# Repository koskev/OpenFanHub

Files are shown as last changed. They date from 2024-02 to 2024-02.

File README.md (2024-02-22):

# OpenFanHub

This project aims to provide plug and play solution for controlling fans and reading temperatures

## Attention
 * The USB-Library is licensed under the SLA0044 License and therefore incompatible with the GPL. Until this is resolved the GPL does not apply to the "Firmware" folder.

## TODO
 * Finish PCB
   * Currently working on a barebone blue pill
   * Probably remove the option for two different µC options
 * Replace USB Lib
 * Implement Rust version as a learning experience?
   * But currently USB hates me :/
 * Replace the USB lib to be compatible with an open source license

## Features
 * Connection for 18 fans
    * 3 Fans form one group
    * 6 independently controllable
    * only one fan in each group reports rpm
    * 3 pin fans are supported but not regulated (I tried it, but ended but beeing to complicated since I plan on using 4 pin anyways)
 * 4 thermistor inputs
 * compatible with the corsair commander pro driver of the kernel
 * Compatible with the "blue pill" boards or an stm32f103c8tx in an LQFP48 package
    * The goal is to make is easy to solder and LQFP48 can be hard

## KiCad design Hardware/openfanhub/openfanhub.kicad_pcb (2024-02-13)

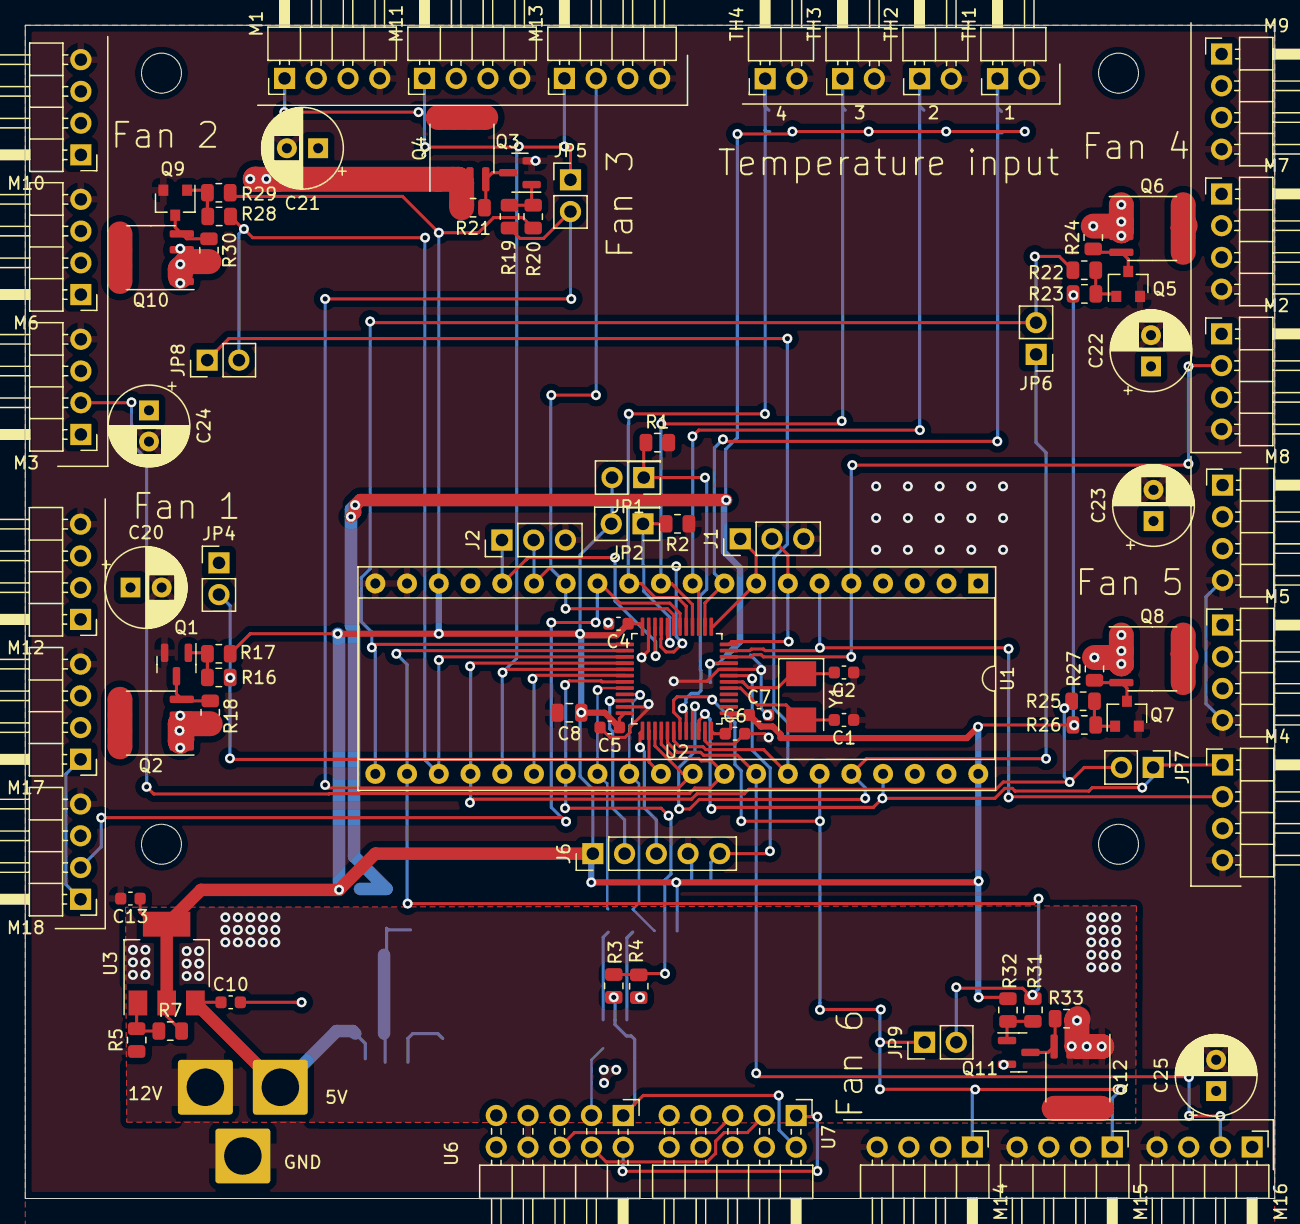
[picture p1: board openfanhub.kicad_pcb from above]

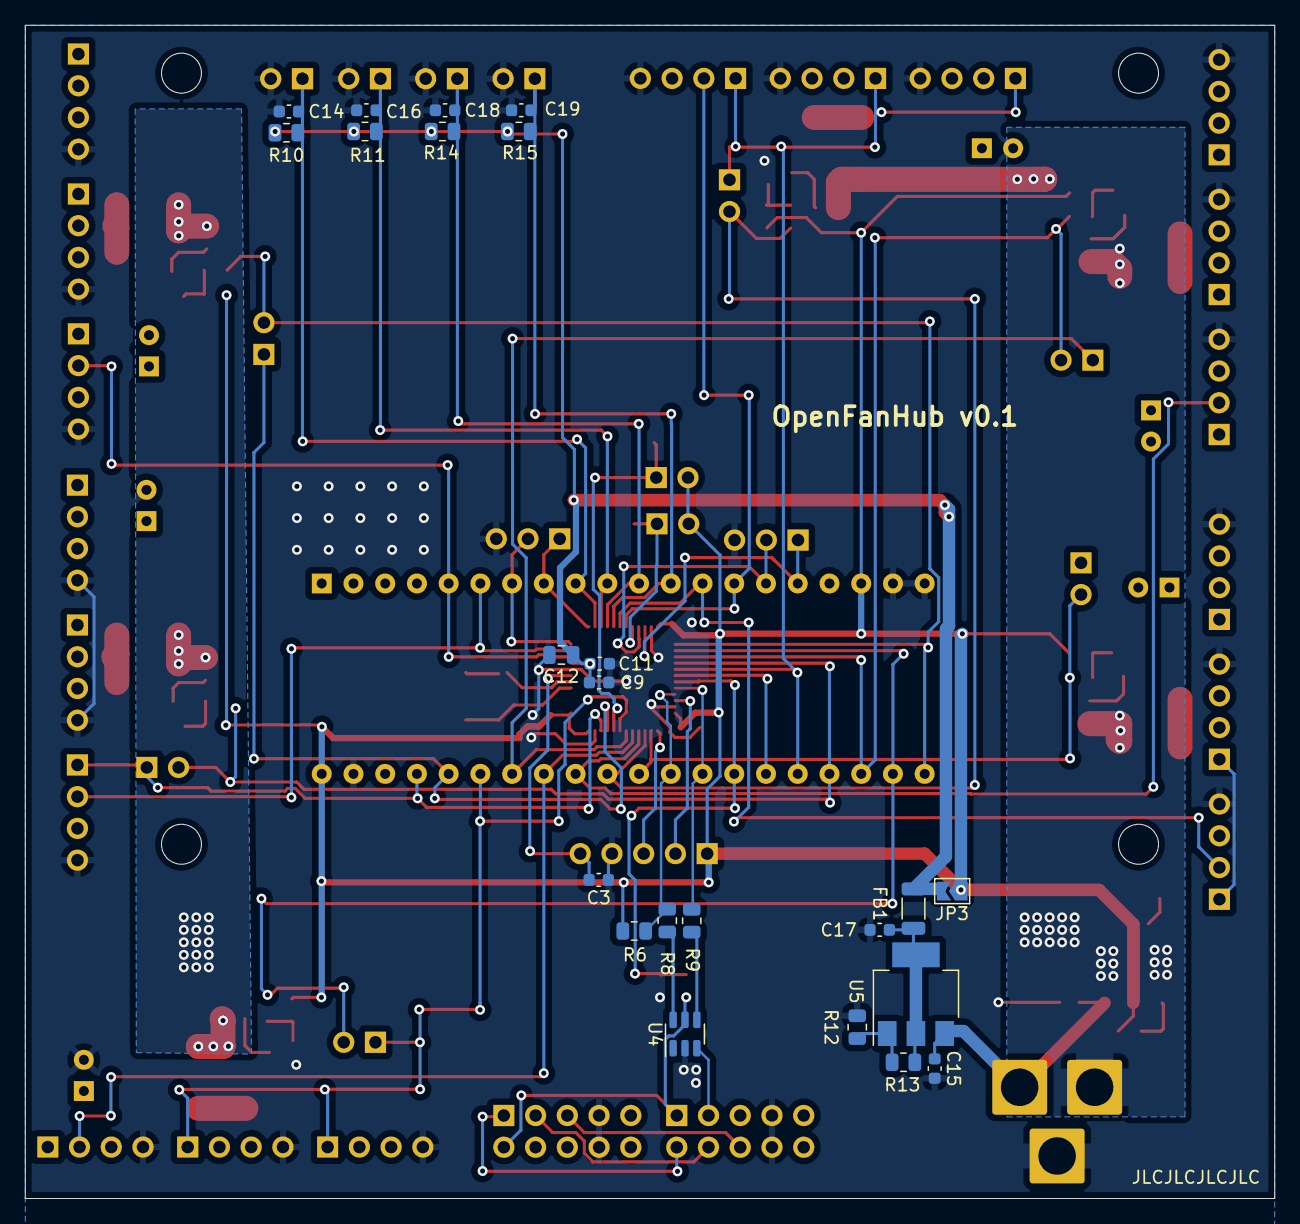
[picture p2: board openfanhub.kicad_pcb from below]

Board: 2 copper layers, 100.0 x 93.9 mm, 120 parts (23 on the bottom side), 70 nets.

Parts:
C1, C2: 22pF; C_0603_1608Metric
C3, C4, C5, C6, C7, C9: 100nF; C_0603_1608Metric
C8, C12: 10µF; C_0805_2012Metric
C10, C13, C14, C15, C16, C17, C18, C19: C; C_0603_1608Metric
C11: 10nF; C_0603_1608Metric
C20, C21, C22, C23, C24, C25: C_Polarized; CP_Radial_D6.3mm_P2.50mm
FB1: FerriteBead; L_1206_3216Metric
H1, H2, H3, H4: MountingHole; MountingHole_3.2mm_M3
J1: UART; PinHeader_1x03_P2.54mm_Vertical
J2: I2C; PinHeader_1x03_P2.54mm_Vertical
J3: 12V in; SolderWire-2.5sqmm_1x01_D2.4mm_OD4.4mm
J4: GND in; SolderWire-2.5sqmm_1x01_D2.4mm_OD4.4mm
J5: 5V IN; SolderWire-2.5sqmm_1x01_D2.4mm_OD4.4mm
J6: SWD; PinHeader_1x05_P2.54mm_Vertical
JP1, JP2: Jumper_2_Open; PinHeader_2x01_P2.54mm_Vertical
JP3: 3.3V connect; SolderJumper-2_P1.3mm_Open_TrianglePad1.0x1.5mm
JP4, JP5, JP6, JP7, JP8, JP9: 3Pin Jumper; PinHeader_1x02_P2.54mm_Vertical
M1, M2, M3, M4, M5, M6, M7, M8, M9, M10, M11, M12, M13, M14, M15, M16, M17, M18: Fan_4pin; PinHeader_1x04_P2.54mm_Horizontal
Q1, Q3, Q5, Q7, Q9, Q11: IRLML2502; SOT-23
Q2, Q4, Q6, Q8, Q10, Q12: AO4409; SOIC-8_3.9x4.9mm_P1.27mm
R1, R2: 10k; R_0805_2012Metric
R3, R4, R5, R6, R7, R8, R9, R10, R11, R12, R13, R14, R15, R16, R17, R18, R19, R20, R21, R22, R23, R24, R25, R26, R27, R28, R29, R30, R31, R32, R33: R; R_0805_2012Metric
TH1, TH2, TH3, TH4: Thermistor; PinHeader_1x02_P2.54mm_Horizontal
U1: STM32F103C8T8_Board; DIP-40_W15.24mm_Socket
U2: STM32F103C8Tx; LQFP-48_7x7mm_P0.5mm
U3, U5: AMS1117; SOT-223
U4: USBLC6-2SC6; SOT-23-6
U6: USB_HEADER_IN; PinHeader_2x05_P2.54mm_Horizontal
U7: USB_HEADER_OUT; PinHeader_2x05_P2.54mm_Horizontal
Y1: Crystal; Crystal_SMD_5032-2Pin_5.0x3.2mm

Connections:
+3.3VA: C9.1, C11.1, C12.1, FB1.2, JP3.2 (B), R10.1, R11.1, R14.1, R15.1, U2.9 (VDDA)
+3V3: C4.1, C5.1, C6.1, C7.1, C8.1, C13.1, J6.1, JP1.2 (B), JP2.2 (B), JP3.1 (A), R6.2, R7.2, R17.1, R20.1, R23.1, R26.1, R29.1, R32.1, U1.18 (3.3V), U1.40 (3.3V), U2.1 (VBAT), U2.24 (VDD), U2.36 (VDD), U2.48 (VDD), U3.2 (Vout), U3.4 (Vout)
+5V: C10.1, C15.1, J5.1, U3.3 (Vin), U5.3 (Vin)
+12V: J3.1, Q2.1 (S), Q2.2 (S), Q2.3 (S), Q4.1 (S), Q4.2 (S), Q4.3 (S), Q6.1 (S), Q6.2 (S), Q6.3 (S), Q8.1 (S), Q8.2 (S), Q8.3 (S), Q10.1 (S), Q10.2 (S), Q10.3 (S), Q12.1 (S), Q12.2 (S), Q12.3 (S), R18.2, R21.2, R24.2, R27.2, R30.2, R33.2
/BOOT0: JP1.1 (A), R1.1, U2.44 (BOOT0)
/BOOT1: JP2.1 (A), R2.2, U2.20 (PB2)
/D1+: U4.1 (I/O1), U6.5 (D1+)
/D1-: U4.3 (I/O2), U6.3 (D1-)
/FAN1_PWM: JP6.1 (A), M2.1 (PWM), M7.1 (PWM), M9.1 (PWM), U1.36 (B8), U2.45 (PB8)
/FAN1_RPM: M2.2 (Tacho), U1.5 (A0), U2.10 (PA0)
/FAN1_SWITCH: JP6.2 (B), R22.2, U1.21 (B12), U2.25 (PB12)
/FAN2_PWM: JP7.1 (A), M4.1 (PWM), M5.1 (PWM), M8.1 (PWM), U1.37 (B9), U2.46 (PB9)
/FAN2_RPM: M4.2 (Tacho), U1.6 (A1), U2.11 (PA1)
/FAN2_SWITCH: JP7.2 (B), R25.2, U1.24 (B15), U2.28 (PB15)
/FAN3_PWM: JP8.1 (A), M3.1 (PWM), M6.1 (PWM), M10.1 (PWM), U1.34 (B6), U2.42 (PB6)
/FAN3_RPM: M3.2 (Tacho), U1.32 (B4), U2.40 (PB4)
/FAN3_SWITCH: JP8.2 (B), R28.2, U1.23 (B14), U2.27 (PB14)
/FAN4_PWM: JP9.1 (A), M14.1 (PWM), M15.1 (PWM), M16.1 (PWM), U1.35 (B7), U2.43 (PB7)
/FAN4_RPM: M16.2 (Tacho), U1.33 (B5), U2.41 (PB5)
/FAN4_SWITCH: JP9.2 (B), R31.2, U1.22 (B13), U2.26 (PB13)
/FAN5_PWM: JP4.1 (A), M12.1 (PWM), M17.1 (PWM), M18.1 (PWM), U1.26 (A9), U2.30 (PA9)
/FAN5_RPM: M18.2 (Tacho), U1.13 (B0), U2.18 (PB0)
/FAN5_SWITCH: JP4.2 (B), R16.2, U1.30 (A15), U2.38 (PA15)
/FAN6_PWM: JP5.1 (A), M1.1 (PWM), M11.1 (PWM), M13.1 (PWM), U1.25 (A8), U2.29 (PA8)
/FAN6_RPM: M13.2 (Tacho), U1.14 (B1), U2.19 (PB1)
/FAN6_SWITCH: JP5.2 (B), R19.2, U1.31 (B3), U2.39 (PB3)
/NRST: C3.2, J6.5, U2.7 (NRST)
/PWM_GROUPS/PWM_GROUP1/SWITCHED_POWER: C22.1, M2.3 (+), M7.3 (+), M9.3 (+), Q6.5 (D), Q6.6 (D), Q6.7 (D), Q6.8 (D)
/PWM_GROUPS/PWM_GROUP2/SWITCHED_POWER: C23.1, M4.3 (+), M5.3 (+), M8.3 (+), Q8.5 (D), Q8.6 (D), Q8.7 (D), Q8.8 (D)
/PWM_GROUPS/PWM_GROUP3/SWITCHED_POWER: C24.1, M3.3 (+), M6.3 (+), M10.3 (+), Q10.5 (D), Q10.6 (D), Q10.7 (D), Q10.8 (D)
/PWM_GROUPS/PWM_GROUP4/SWITCHED_POWER: C25.1, M14.3 (+), M15.3 (+), M16.3 (+), Q12.5 (D), Q12.6 (D), Q12.7 (D), Q12.8 (D)
/PWM_GROUPS/PWM_GROUP5/SWITCHED_POWER: C20.1, M12.3 (+), M17.3 (+), M18.3 (+), Q2.5 (D), Q2.6 (D), Q2.7 (D), Q2.8 (D)
/PWM_GROUPS/PWM_GROUP6/SWITCHED_POWER: C21.1, M1.3 (+), M11.3 (+), M13.3 (+), Q4.5 (D), Q4.6 (D), Q4.7 (D), Q4.8 (D)
/SCL: J2.2, U1.15 (B10), U2.21 (PB10)
/SDA: J2.1, U1.16 (B11), U2.22 (PB11)
/SWD_CLK: J6.3, U2.37 (PA14)
/SWD_IO: J6.2, U2.34 (PA13)
/TEMP1_IN: C14.1, R10.2, TH1.1, U1.9 (A4), U2.14 (PA4)
/TEMP2_IN: C16.1, R11.2, TH2.1, U1.10 (A5), U2.15 (PA5)
/TEMP3_IN: C18.1, R14.2, TH3.1, U1.11 (A6), U2.16 (PA6)
/TEMP4_IN: C19.1, R15.2, TH4.1, U1.12 (A7), U2.17 (PA7)
/UART_RX: J1.1, U1.8 (A3), U2.13 (PA3)
/UART_TX: J1.2, U1.7 (A2), U2.12 (PA2)
/USB_D+: R6.1, R8.1, U1.29 (A12), U2.33 (PA12)
/USB_D-: R9.1, U1.28 (A11), U2.32 (PA11)
/VBUS: R3.1, U4.5 (VBUS), U6.1 (5V), U7.2 (5V)
/VBUS_SENSE: R3.2, R4.1, U1.27 (A10), U2.31 (PA10)
GND: C1.1, C2.1, C3.1, C4.2, C5.2, C6.2, C7.2, C8.2, C9.2, C10.2, C11.2, C12.2, C13.2, C14.2, C15.2, C16.2, C17.2, C18.2, C19.2, C20.2, C21.2, C22.2, C23.2, C24.2, C25.2, J1.3, J2.3, J4.1, J6.4, M1.4 (-), M2.4 (-), M3.4 (-), M4.4 (-), M5.4 (-), M6.4 (-), M7.4 (-), M8.4 (-), M9.4 (-), M10.4 (-), M11.4 (-), M12.4 (-), M13.4 (-), M14.4 (-), M15.4 (-), M16.4 (-), M17.4 (-), M18.4 (-), Q1.2 (S), Q3.2 (S), Q5.2 (S), Q7.2 (S), Q9.2 (S), Q11.2 (S), R1.2, R2.1, R4.2, R5.1, R12.1, TH1.2, TH2.2, TH3.2, TH4.2, U1.19 (GND), U1.20 (GND), U1.39 (GND), U2.8 (VSSA), U2.23 (VSS), U2.35 (VSS), U2.47 (VSS), U4.2 (GND), U6.7 (GND), U6.8 (GND), U7.7 (GND), U7.8 (GND)
unnamed: C1.2, U2.5 (PD0), Y1.2
unnamed: C2.2, U2.6 (PD1), Y1.1
unnamed: C17.1, FB1.1, R13.2, U5.2 (Vout), U5.4 (Vout)
unnamed: Q1.1 (G), R16.1, R17.2
unnamed: Q1.3 (D), Q2.4 (G), R18.1
unnamed: Q3.1 (G), R19.1, R20.2
unnamed: Q3.3 (D), Q4.4 (G), R21.1
unnamed: Q5.1 (G), R22.1, R23.2
unnamed: Q5.3 (D), Q6.4 (G), R24.1
unnamed: Q7.1 (G), R25.1, R26.2
unnamed: Q7.3 (D), Q8.4 (G), R27.1
unnamed: Q9.1 (G), R28.1, R29.2
unnamed: Q9.3 (D), Q10.4 (G), R30.1
unnamed: Q11.1 (G), R31.1, R32.2
unnamed: Q11.3 (D), Q12.4 (G), R33.1
unnamed: R5.2, R7.1, U3.1 (ADJ)
unnamed: R8.2, U4.6 (I/O1)
unnamed: R9.2, U4.4 (I/O2)
unnamed: R12.2, R13.1, U5.1 (ADJ)
unnamed: U6.2 (5V), U7.1 (5V)
unnamed: U6.4 (D2-), U7.3 (D1-)
unnamed: U6.6 (D2+), U7.5 (D1+)

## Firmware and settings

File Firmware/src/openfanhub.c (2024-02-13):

#include "STM32F1/Drivers/STM32F1xx_HAL_Driver/Inc/stm32f1xx_hal_gpio.h"
#include "adc.h"
#include "stm32f1xx.h"
#include "STM32F1/Drivers/STM32F1xx_HAL_Driver/Inc/stm32f1xx_hal_flash.h"
#include <cmsis_gcc.h>
#include <stm32f103xb.h>
#include <stm32f1xx_hal.h>
#include <stm32f1xx_hal_conf.h>
#include <main.h>
#include <adc.h>
#include <dma.h>
#include <i2c.h>
#include <tim.h>
#include <usart.h>
#include <usb_device.h>
#include <gpio.h>

#include "STM32F1/Inc/usbd_custom_hid_if.h"
#include "stm32f1xx_hal_adc.h"
#include "stm32f1xx_hal_tim.h"

#include <gpio.h>

#include <stdint.h>
#include <string.h>

#include "config.h"

#include "lib/logf.h"

#include "fan.h"

volatile uint16_t temps[4] = {0};

/**
 * Notes Fan:
 * PWM
 * https://www.glkinst.com/cables/cable_pics/4_Wire_PWM_Spec.pdf
 * https://noctua.at/pub/media/wysiwyg/Noctua_PWM_specifications_white_paper.pdf
 * 	25kHz, acceptable range 21kHz to 28kHz
 * 		freq doesn't seem to matter at all. even worked with a 18hz signal
 * 	max: 5,25V 
 * 	low: 0.8V
 * 		3.3V PWM works fine
 * 	pulled high
 * 		max 5.25v. rec 3.3v
 * 	fan pulls tacho signal low on pass
 * 		pull up for desired voltage
 *
 *
 */

extern int8_t USBD_CUSTOM_HID_SendReport_FS ( uint8_t *report,uint16_t len);
extern TIM_HandleTypeDef htim1;
extern TIM_HandleTypeDef htim2;
extern TIM_HandleTypeDef htim3;
extern TIM_HandleTypeDef htim4;
extern ADC_HandleTypeDef hadc1;

enum CONTROL {
	CTL_GET_TMP_CNCT = 0x10,
	CTL_GET_TMP = 0x11,
	CTL_GET_FAN_CNCT = 0x20,
	CTL_GET_FAN_RPM = 0x21,
	CTL_GET_FAN_PWM = 0x22,
	CTL_SET_FAN_FPWM = 0x23,
	CTL_SET_FAN_TARGET = 0x24
};

#define RESPONSE_SIZE 16
#define NUM_FANS 6 // limited by the driver
#define NUM_TEMP_SENSORS 4


static fan_handle_t fans[NUM_FANS];


float steinhart(int res, float a0, float a1, float a2) {
	float res_log = logf(res);
	return 1. / (a0 + a1 * res_log + a2 * res_log*res_log);
}

uint16_t get_temp(int temp_id) {
	int voltage_mv = ((float)ADC_VREF/(1 << ADC_BITS)) * temps[temp_id]; 
	int resistance = TEMP_R1 * (1/(((float)ADC_VREF/voltage_mv) - 1));
	float temp_k = steinhart(resistance, TEMP1_COEFFA, TEMP1_COEFFB, TEMP1_COEFFC);
	return (temp_k - 275.15)*100;
}


void on_usb_rx(void* data) {
	uint8_t* data_8 = (uint8_t*) data;
	static uint8_t response[RESPONSE_SIZE];
	memset(response, 0, RESPONSE_SIZE);
	uint8_t command_id = data_8[0];
	switch(command_id) {
		case CTL_GET_TMP_CNCT:
			// fill byte 1-4 with 1 if a temp probe is present
			for(int i = 0; i < NUM_TEMP_SENSORS; ++i) {
				response[i+1] = 0x01;
			}
			break;
		case CTL_GET_FAN_CNCT:
			for(int i = 0; i < NUM_FANS; ++i) {
				response[i+1] = get_fan_type(&fans[i]);
			}
			break;
		case CTL_GET_FAN_RPM:
			{
				uint16_t rpm = get_fan_rpm(&fans[data_8[1]]);
				response[1] = rpm >> 8;
				response[2] = rpm;

			}
			break;
		case CTL_GET_FAN_PWM:
			{
				uint8_t pwm = get_fan_pwm(&fans[data_8[1]]);
				response[1] = pwm;
			}
			break;
		case CTL_SET_FAN_FPWM:
			{
				uint8_t fan_num = data_8[1];
				uint8_t percentage = data_8[2];
				set_fan_pwm_percentage(&fans[fan_num], percentage);
			}
			break;
		case CTL_GET_TMP:
			{
				uint16_t temp = get_temp(data_8[1]);
				response[1] = temp >> 8;
				response[2] = temp;
			}
			break;
		default:
			break;
	};
	USBD_CUSTOM_HID_SendReport_FS(response, 16);
	HAL_GPIO_TogglePin(GPIOC, GPIO_PIN_13);
}



void init_fans() {
	//TODO: yeah I hate it
	init_fan(&fans[0], FAN1_PWM_TIMER, FAN1_PWM_CHANNEL, FAN1_IC_TIMER, FAN1_IC_CHANNEL, FAN1_IC_CHANNEL_ACTIVE, FAN1_PWM_PORT, FAN1_PWM_PIN, FAN1_POWER_SWITCH_PORT, FAN1_POWER_SWITCH_PIN);
	init_fan(&fans[1], FAN2_PWM_TIMER, FAN2_PWM_CHANNEL, FAN2_IC_TIMER, FAN2_IC_CHANNEL, FAN2_IC_CHANNEL_ACTIVE, FAN2_PWM_PORT, FAN2_PWM_PIN, FAN2_POWER_SWITCH_PORT, FAN2_POWER_SWITCH_PIN);
	init_fan(&fans[2], FAN3_PWM_TIMER, FAN3_PWM_CHANNEL, FAN3_IC_TIMER, FAN3_IC_CHANNEL, FAN3_IC_CHANNEL_ACTIVE, FAN3_PWM_PORT, FAN3_PWM_PIN, FAN3_POWER_SWITCH_PORT, FAN3_POWER_SWITCH_PIN);
	init_fan(&fans[3], FAN4_PWM_TIMER, FAN4_PWM_CHANNEL, FAN4_IC_TIMER, FAN4_IC_CHANNEL, FAN4_IC_CHANNEL_ACTIVE, FAN4_PWM_PORT, FAN4_PWM_PIN, FAN4_POWER_SWITCH_PORT, FAN4_POWER_SWITCH_PIN);
	init_fan(&fans[4], FAN5_PWM_TIMER, FAN5_PWM_CHANNEL, FAN5_IC_TIMER, FAN5_IC_CHANNEL, FAN5_IC_CHANNEL_ACTIVE, FAN5_PWM_PORT, FAN5_PWM_PIN, FAN5_POWER_SWITCH_PORT, FAN5_POWER_SWITCH_PIN);
	init_fan(&fans[5], FAN6_PWM_TIMER, FAN6_PWM_CHANNEL, FAN6_IC_TIMER, FAN6_IC_CHANNEL, FAN6_IC_CHANNEL_ACTIVE, FAN6_PWM_PORT, FAN6_PWM_PIN, FAN6_POWER_SWITCH_PORT, FAN6_POWER_SWITCH_PIN);
}

void HAL_TIM_IC_CaptureCallback(TIM_HandleTypeDef *htim) {
	for(int i = 0; i < NUM_FANS; ++i) {
		volatile fan_handle_t *fan = &fans[i];
		if(fan->ic_handle->Instance == htim->Instance && fan->ic_channel_active == htim->Channel) {

			uint32_t curr_val = HAL_TIM_ReadCapturedValue(fan->ic_handle, fan->ic_channel);
			uint32_t diff = (curr_val+fan->ic_overflow*htim->Init.Period) - fan->last_val;

			if(diff != 0) {
				uint32_t freq = (72000000.0f/htim->Init.Prescaler)/diff;
				fan->rpm = freq * 30; // 2 pulses = one rev
			}

			fan->last_val = curr_val;
			fan->ic_overflow = 0;
			break;
		}
	}
}

void HAL_TIM_PeriodElapsedCallback(TIM_HandleTypeDef* htim) {
	for(int i = 0; i < NUM_FANS; ++i) {
		volatile fan_handle_t *fan = &fans[i];
		if(fan->ic_handle->Instance == htim->Instance) {
			fans[i].ic_overflow +=1;
			if(fans[i].ic_overflow > 5) {
				fans[i].rpm = 0;
			}
		}
	}
}

void read_adc() {
	//HAL_ADC_Start_IT(&hadc1);
	HAL_ADC_Start_DMA(&hadc1, (uint32_t*)&temps, 4);
}

void init_system_clock(void) {
	RCC_OscInitTypeDef RCC_OscInitStruct = {0};
	RCC_ClkInitTypeDef RCC_ClkInitStruct = {0};
	RCC_PeriphCLKInitTypeDef PeriphClkInit = {0};
	
	/** Initializes the RCC Oscillators according to the specified parameters
	* in the RCC_OscInitTypeDef structure.
	*/
	RCC_OscInitStruct.OscillatorType = RCC_OSCILLATORTYPE_HSE;
	RCC_OscInitStruct.HSEState = RCC_HSE_ON;
	RCC_OscInitStruct.HSEPredivValue = RCC_HSE_PREDIV_DIV1;
	RCC_OscInitStruct.HSIState = RCC_HSI_ON;
	RCC_OscInitStruct.PLL.PLLState = RCC_PLL_ON;
	RCC_OscInitStruct.PLL.PLLSource = RCC_PLLSOURCE_HSE;
	RCC_OscInitStruct.PLL.PLLMUL = RCC_PLL_MUL9;
	if (HAL_RCC_OscConfig(&RCC_OscInitStruct) != HAL_OK)
	{
	  Error_Handler();
	}
	/** Initializes the CPU, AHB and APB buses clocks
	*/
	RCC_ClkInitStruct.ClockType = RCC_CLOCKTYPE_HCLK|RCC_CLOCKTYPE_SYSCLK
	                            |RCC_CLOCKTYPE_PCLK1|RCC_CLOCKTYPE_PCLK2;
	RCC_ClkInitStruct.SYSCLKSource = RCC_SYSCLKSOURCE_PLLCLK;
	RCC_ClkInitStruct.AHBCLKDivider = RCC_SYSCLK_DIV1;
	RCC_ClkInitStruct.APB1CLKDivider = RCC_HCLK_DIV2;
	RCC_ClkInitStruct.APB2CLKDivider = RCC_HCLK_DIV1;
	
	if (HAL_RCC_ClockConfig(&RCC_ClkInitStruct, FLASH_LATENCY_2) != HAL_OK)
	{
	  Error_Handler();
	}
	PeriphClkInit.PeriphClockSelection = RCC_PERIPHCLK_ADC|RCC_PERIPHCLK_USB;
	PeriphClkInit.AdcClockSelection = RCC_ADCPCLK2_DIV6;
	PeriphClkInit.UsbClockSelection = RCC_USBCLKSOURCE_PLL_DIV1_5;
	if (HAL_RCCEx_PeriphCLKConfig(&PeriphClkInit) != HAL_OK)
	{
	  Error_Handler();
	}
}

void init() {
	HAL_Init();

	init_system_clock();
	MX_GPIO_Init();
	MX_TIM1_Init();
	MX_TIM2_Init();
	MX_TIM3_Init();
	MX_TIM4_Init();
	MX_USB_DEVICE_Init();
	MX_DMA_Init();
	MX_ADC1_Init();
	MX_I2C2_Init();
	MX_USART2_UART_Init();
	
}

int main() {
	for(int i = 0; i < sizeof(fan_handle_t) * NUM_FANS; ++i) {
		*((volatile uint8_t*)fans+i) = 0;
	}
	init();
	HAL_ADCEx_Calibration_Start(&hadc1);
	HAL_ADC_Start_DMA(&hadc1, (uint32_t*)&temps, 4);
	
	
	/**
	 * TODO:
	 * 	push usb commands in a queue
	 * 		less volatile needed
	 * 		same possible for ic?
	 */
	init_fans();
	
	while(42) {
		__WFI();
	}
}

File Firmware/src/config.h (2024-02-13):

#define ADC_VREF 3300
#define ADC_BITS 12
#define TEMP_R1 10000
#define TEMP1_COEFFA 1.02440469e-03
#define TEMP1_COEFFB 2.06924335e-04
#define TEMP1_COEFFC 5.07042776e-06

#define TIMER1_HANDLE &htim1
#define TIMER2_HANDLE &htim2
#define TIMER3_HANDLE &htim3
#define TIMER4_HANDLE &htim4

#define FAN1_PWM_TIMER TIMER1_HANDLE
#define FAN1_PWM_CHANNEL TIM_CHANNEL_1
#define FAN1_PWM_PORT GPIOA
#define FAN1_PWM_PIN GPIO_PIN_8
#define FAN1_IC_TIMER TIMER2_HANDLE
#define FAN1_IC_CHANNEL TIM_CHANNEL_1
#define FAN1_IC_CHANNEL_ACTIVE HAL_TIM_ACTIVE_CHANNEL_1
#define FAN1_POWER_SWITCH_PORT GPIOB
#define FAN1_POWER_SWITCH_PIN GPIO_PIN_12

#define FAN2_PWM_TIMER TIMER1_HANDLE
#define FAN2_PWM_CHANNEL TIM_CHANNEL_2
#define FAN2_PWM_PORT GPIOA
#define FAN2_PWM_PIN GPIO_PIN_9
#define FAN2_IC_TIMER TIMER2_HANDLE
#define FAN2_IC_CHANNEL TIM_CHANNEL_2
#define FAN2_IC_CHANNEL_ACTIVE HAL_TIM_ACTIVE_CHANNEL_2
#define FAN2_POWER_SWITCH_PORT GPIOB
#define FAN2_POWER_SWITCH_PIN GPIO_PIN_13

#define FAN3_PWM_TIMER TIMER4_HANDLE
#define FAN3_PWM_CHANNEL TIM_CHANNEL_1
#define FAN3_PWM_PORT GPIOB
#define FAN3_PWM_PIN GPIO_PIN_6
#define FAN3_IC_TIMER TIMER3_HANDLE
#define FAN3_IC_CHANNEL TIM_CHANNEL_1
#define FAN3_IC_CHANNEL_ACTIVE HAL_TIM_ACTIVE_CHANNEL_1
#define FAN3_POWER_SWITCH_PORT GPIOB
#define FAN3_POWER_SWITCH_PIN GPIO_PIN_14

#define FAN4_PWM_TIMER TIMER4_HANDLE
#define FAN4_PWM_CHANNEL TIM_CHANNEL_2
#define FAN4_PWM_PORT GPIOB
#define FAN4_PWM_PIN GPIO_PIN_7
#define FAN4_IC_TIMER TIMER3_HANDLE
#define FAN4_IC_CHANNEL TIM_CHANNEL_2
#define FAN4_IC_CHANNEL_ACTIVE HAL_TIM_ACTIVE_CHANNEL_2
#define FAN4_POWER_SWITCH_PORT GPIOB
#define FAN4_POWER_SWITCH_PIN GPIO_PIN_15

#define FAN5_PWM_TIMER TIMER4_HANDLE
#define FAN5_PWM_CHANNEL TIM_CHANNEL_3
#define FAN5_PWM_PORT GPIOB
#define FAN5_PWM_PIN GPIO_PIN_8
#define FAN5_IC_TIMER TIMER3_HANDLE
#define FAN5_IC_CHANNEL TIM_CHANNEL_3
#define FAN5_IC_CHANNEL_ACTIVE HAL_TIM_ACTIVE_CHANNEL_3
#define FAN5_POWER_SWITCH_PORT GPIOA
#define FAN5_POWER_SWITCH_PIN GPIO_PIN_15

#define FAN6_PWM_TIMER TIMER4_HANDLE
#define FAN6_PWM_CHANNEL TIM_CHANNEL_4
#define FAN6_PWM_PORT GPIOB
#define FAN6_PWM_PIN GPIO_PIN_9
#define FAN6_IC_TIMER TIMER3_HANDLE
#define FAN6_IC_CHANNEL TIM_CHANNEL_4
#define FAN6_IC_CHANNEL_ACTIVE HAL_TIM_ACTIVE_CHANNEL_4
#define FAN6_POWER_SWITCH_PORT GPIOB
#define FAN6_POWER_SWITCH_PIN GPIO_PIN_3

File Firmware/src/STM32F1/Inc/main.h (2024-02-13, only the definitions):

#define FAN1_SWITCH_Pin GPIO_PIN_12
#define FAN1_SWITCH_GPIO_Port GPIOB
#define FAN2_SWITCH_Pin GPIO_PIN_13
#define FAN2_SWITCH_GPIO_Port GPIOB
#define FAN3_SWITCH_Pin GPIO_PIN_14
#define FAN3_SWITCH_GPIO_Port GPIOB
#define FAN4_SWITCH_Pin GPIO_PIN_15
#define FAN4_SWITCH_GPIO_Port GPIOB
#define FAN5_SWITCH_Pin GPIO_PIN_15
#define FAN5_SWITCH_GPIO_Port GPIOA
#define FAN6_SWITCH_Pin GPIO_PIN_3
#define FAN6_SWITCH_GPIO_Port GPIOB

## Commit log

2024-02-13 First working version with all sensors to 0
2024-02-13 Fix wrong descriptor. Still problems with sending data back
    [openfanhub.c]
2024-02-13 Fix problems with corrupted data
    [openfanhub.c]
2024-02-13 Add temperature output
2024-02-13 Fix bInterval and descriptor size in CubeMX
    [STM32F103.ioc]
2024-02-13 Add timer etc
2024-02-13 Rearrange timers
2024-02-13 Update pin feature usage Enable adc, i2c, uart etc.
2024-02-13 Add detection of 4 pin fans. Add config file.
2024-02-13 Update schematics with new pin layout
    [fan_connector.sch, openfanhub.sch, pwm_group.sch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]
2024-02-13 Update timers
2024-02-13 Fix fan init
2024-02-13 Fix timer prescaler and period
    [STM32F103.ioc]
2024-02-13 Idea to enable 3 pin PWM support with minimal components
    [fan_connector.sch]
2024-02-13 Fix switch to deactivate fan
2024-02-13 Enable fan by default (even if µC is offline)
    [fan_connector.sch, pwm_group.sch]
2024-02-13 Update files to kicad 6
    [fan_connector.sch, openfanhub.kicad_pcb, openfanhub.sch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]
2024-02-13 Add support for 4 temp probes. They are constantly read using dma
2024-02-13 Copy init code to openfanhub as cubemx messes up the dma adc init order
2024-02-13 Move fan code to a separate file
2024-02-13 Move more functions in fan file
2024-02-13 Add v6 schematic
    [openfanhub.kicad_sch]
2024-02-13 Add first (badly) routed version. Still need to polish it and check all power/signal paths
    [fan_connector.kicad_sch, openfanhub.kicad_pcb, openfanhub.kicad_sch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]
2024-02-13 First pcb version
    [openfanhub.kicad_pcb, openfanhub.kicad_sch]
2024-02-13 Update PCB. Move Power and USB to the same side
    [fan_connector.kicad_sch, openfanhub.kicad_pcb, openfanhub.kicad_sch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]
2024-02-13 Make PCB smaller
    [openfanhub.kicad_pcb]
2024-02-13 Update silkscreen
    [openfanhub.kicad_pcb]
2024-02-13 Update (not sure what)
    [fan_connector.kicad_sch, openfanhub.kicad_pcb, openfanhub.kicad_sch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]

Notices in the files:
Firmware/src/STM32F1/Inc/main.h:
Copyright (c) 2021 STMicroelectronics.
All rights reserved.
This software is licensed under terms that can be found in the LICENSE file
